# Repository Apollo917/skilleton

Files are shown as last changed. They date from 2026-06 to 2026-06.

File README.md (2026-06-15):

<div align="center">

# Skilleton 10" Server Rack Framework

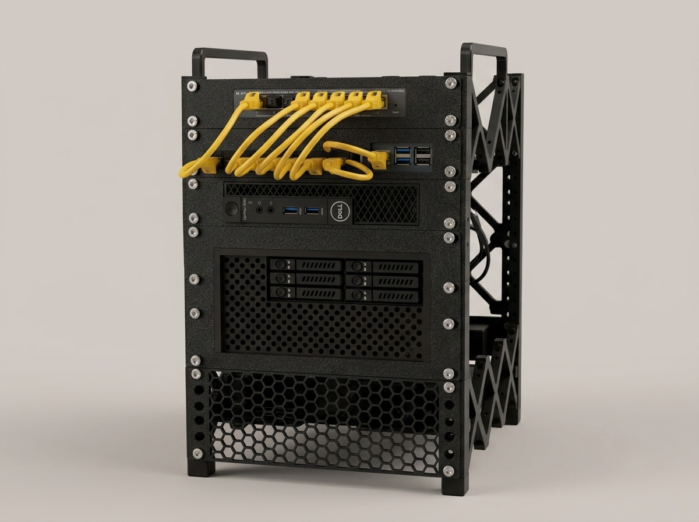
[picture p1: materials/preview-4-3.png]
Shelf mounts


</div>
<br>

**Skilleton** is a fully open-source, 3D-printable framework designed for constructing custom server and network racks
for homelab environments. Built around a modular 1U-factor grid, it allows users to scale, stretch, and compose
enclosures tailored precisely to specific hardware footprints

While optimized natively for 10-inch hardware, Skilleton avoids rigid dimension locks. Its height, width, and depth are
entirely defined by swappable, modular structural segments, making the system fully customizable

🚀 **Key Specifications & Features**

- **1U Grid Modularity:** Highly extensible layout based on standard 1U height intervals
- **Fully Custom Dimensions:** Adaptable width, depth, and height via interchangeable segments to fit non-standard
  hardware
- **Hardware Integration:** Features an integrated captive nut design for robust component mounting and assembly
- **100% 3D Printable:** Optimized for standard desktop 3D printers without requiring specialized manufacturing tools
- **Open Source:** Fully accessible architecture for community modifications and custom segment developments

🏋 **Structural Integrity & Load Ratings**

- **Component Static Load:** Standalone structural PETG segments successfully completed static load testing at **12kg**
  with zero structural failure or permanent deformation
- **Assembled Assembly Capacity:** In active deployment, a fully assembled PETG 8U Skilleton configuration continuously
  supports a **9kg** multi-node homelab setup without structural fatigue

<details>
<summary>Skilleton 8U Server Rack</summary>

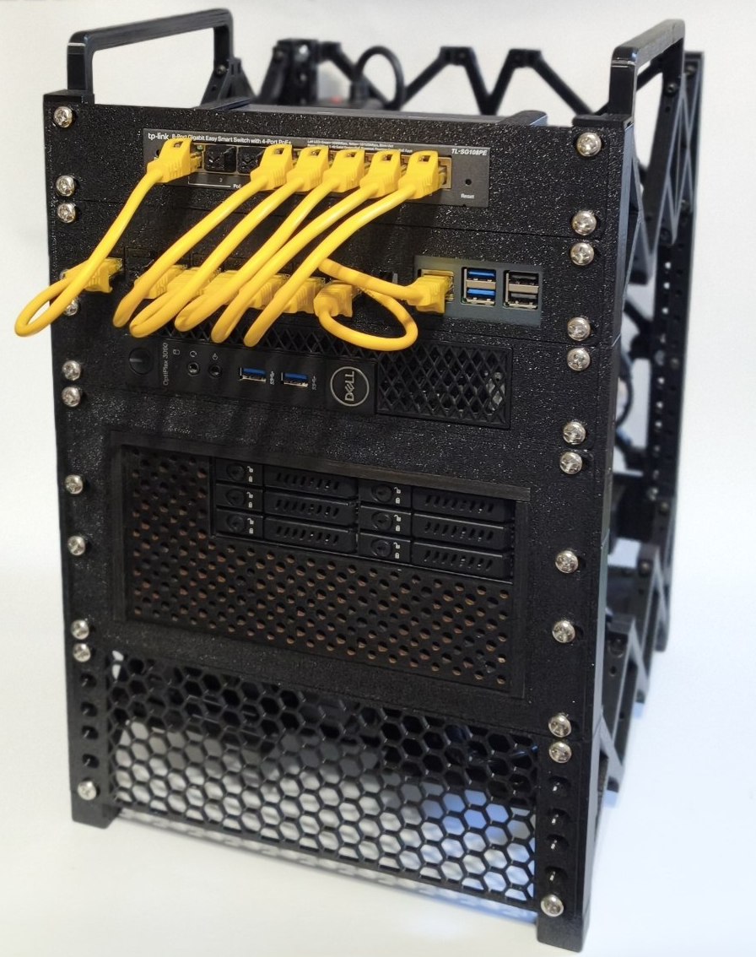
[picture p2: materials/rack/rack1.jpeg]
rack1

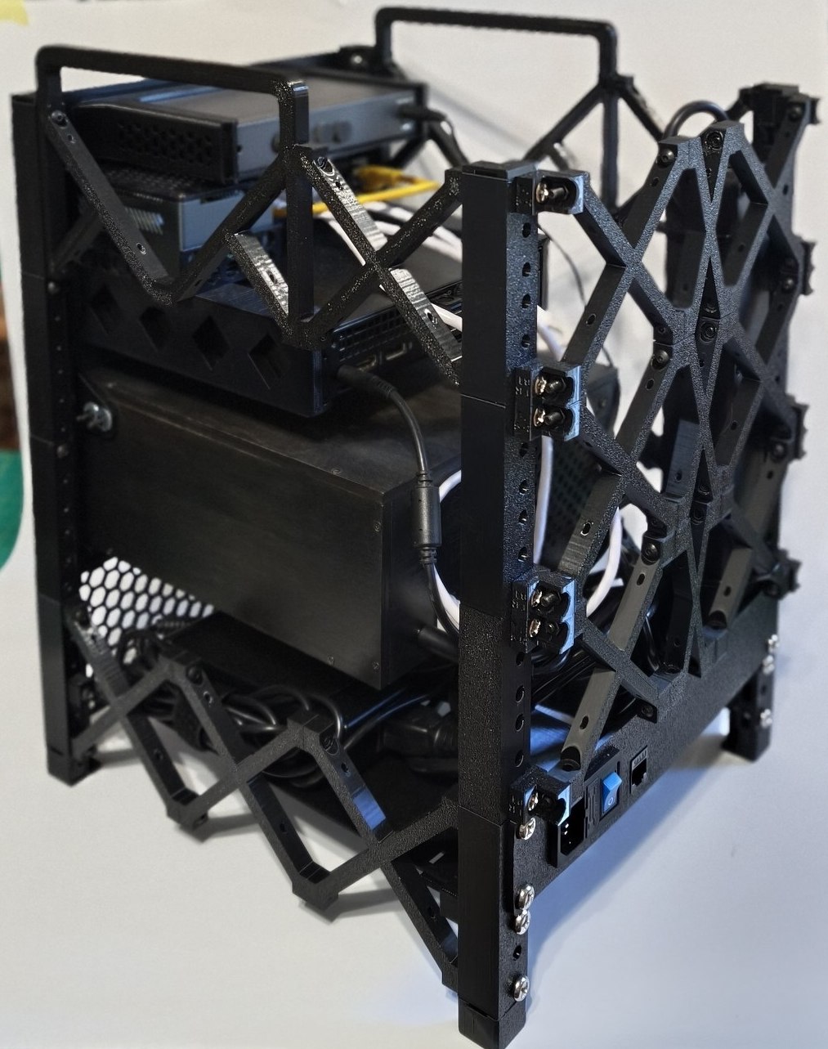
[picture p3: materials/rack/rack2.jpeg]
rack2

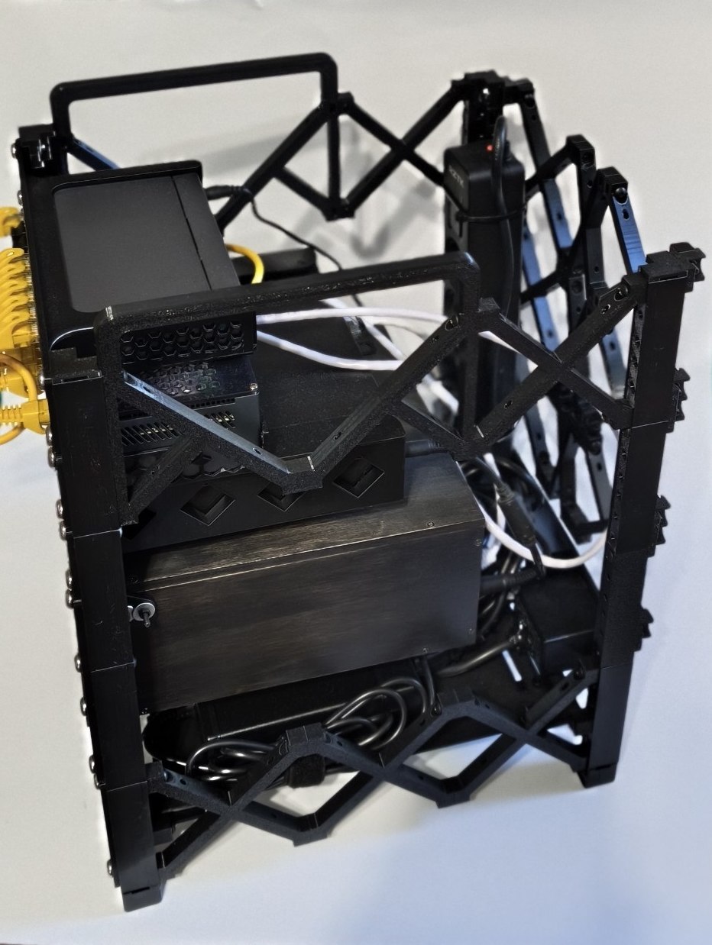
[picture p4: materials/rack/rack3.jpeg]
rack3

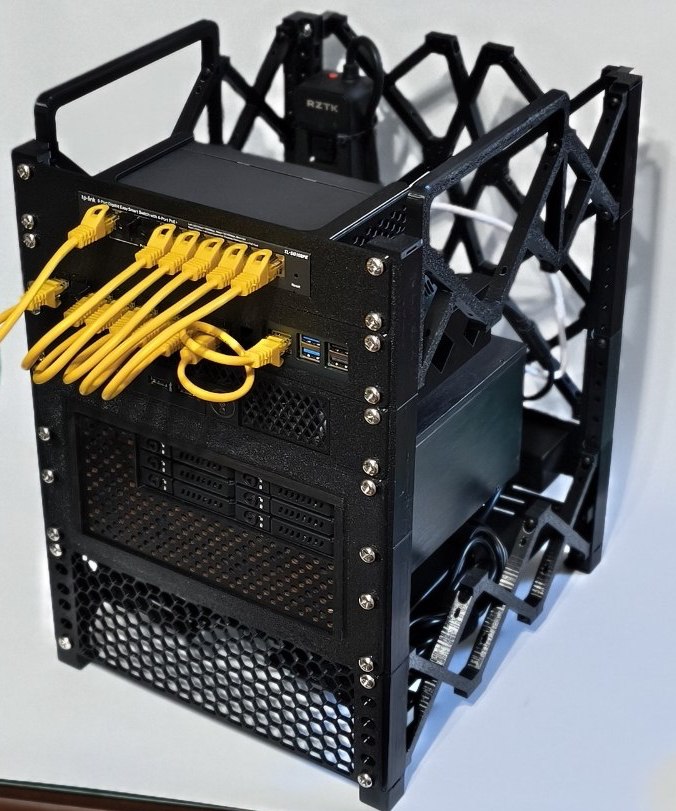
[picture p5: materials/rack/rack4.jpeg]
rack4

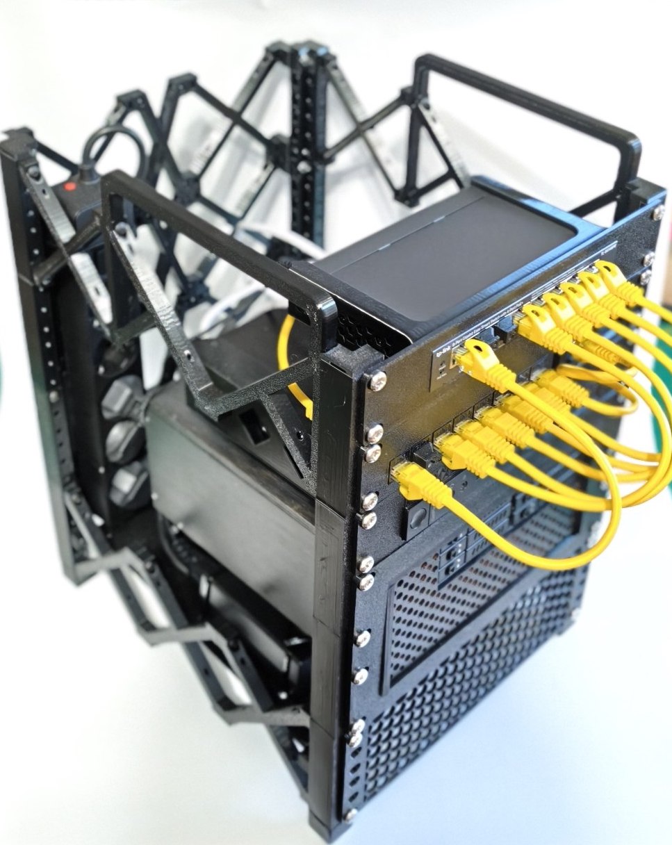
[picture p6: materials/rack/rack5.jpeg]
rack5

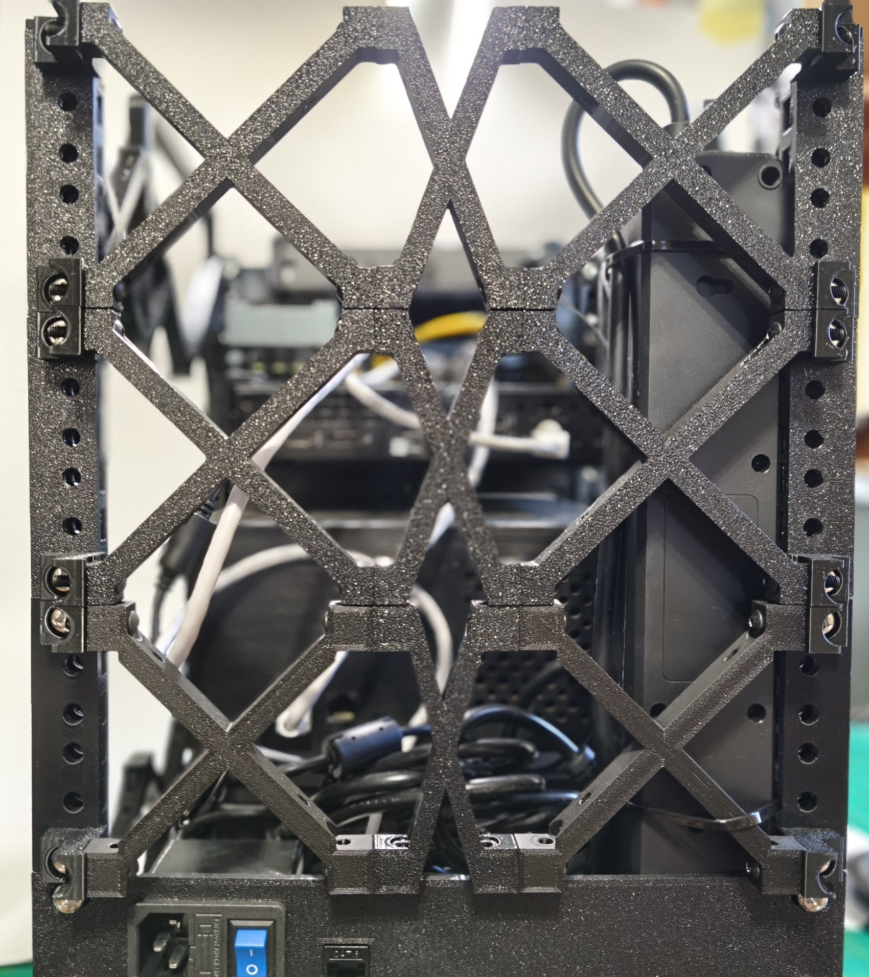
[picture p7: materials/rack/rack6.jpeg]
rack6

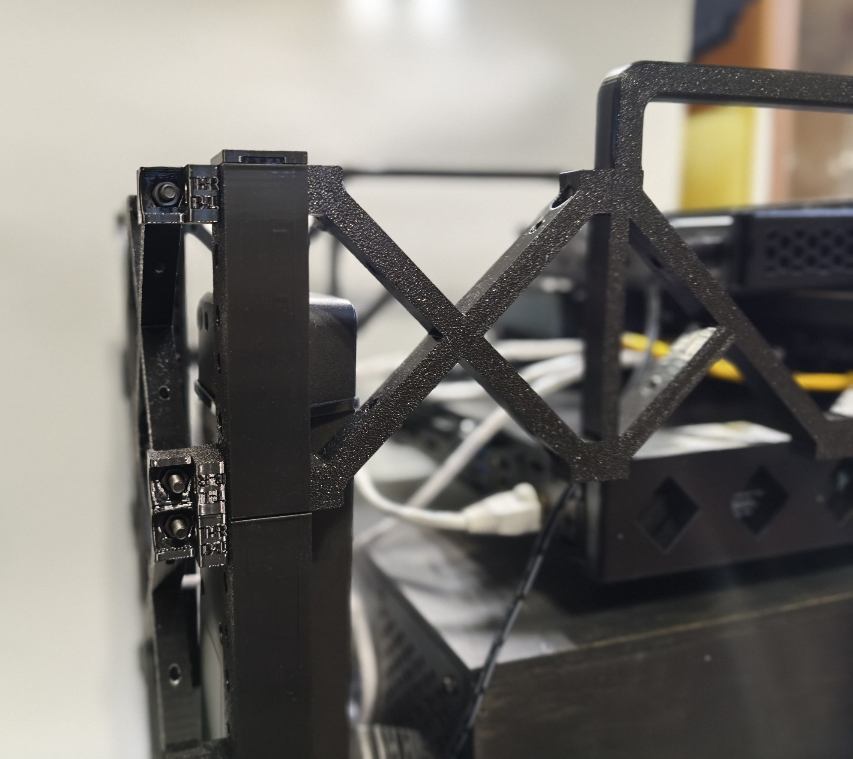
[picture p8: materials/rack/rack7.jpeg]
rack7

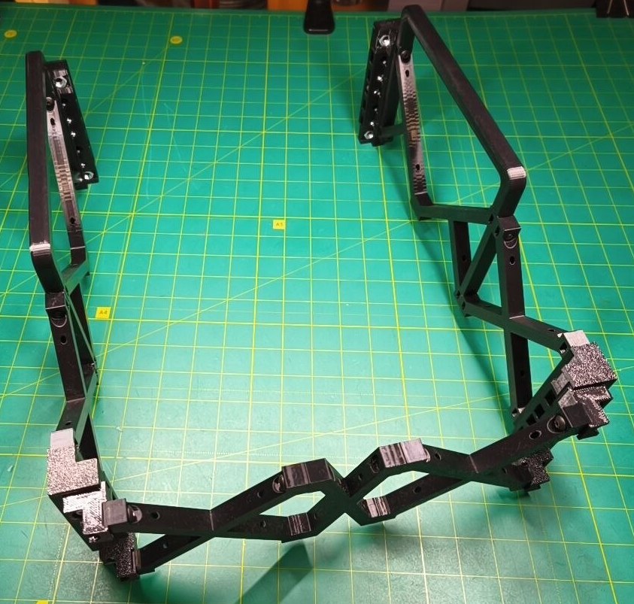
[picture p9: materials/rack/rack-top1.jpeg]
rack-top1

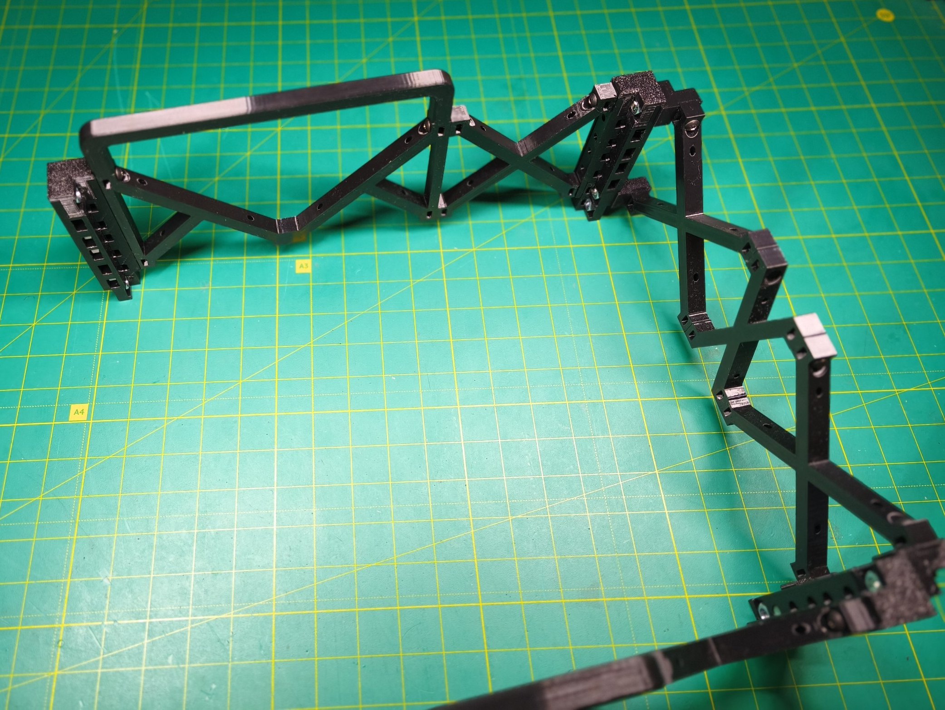
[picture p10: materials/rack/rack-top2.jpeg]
rack-top2


</details>

## 🔗Links

- [Skilleton on MakerWorld](https://makerworld.com/en/models/2936394-skilleton-10-server-rack-framework#profileId-3288012)
- [Skilleton on Printables](https://www.printables.com/model/1755132-skilleton-10-server-rack-framework)

## ⚙️ Print Specifications

A standard 6U Skilleton 10-inch rack configuration requires:

- **Filament:** ~700g of PETG (or technical filaments with equivalent mechanical properties)
- **Time:** ~26 hours
- **Layer Height:** 0.2mm
- **Infill:** 30% Gyroid
- **Wall Loops:**
    - **5 walls** for all handle components
    - **4 walls** for all other structural components

## 🔩 Bill of Materials

Aside from the filament, assembling the **Skilleton** rack requires only standard metric fasteners. All
integrated slots are engineered to fit standard DIN 934 hex nuts, removing the need for proprietary hardware or heat-set
tools

### Material Types

- M4 x 20mm screws
- M4 nuts DIN 934 hex nuts
- M6 x 16mm screws
- M6 nuts DIN 934 hex nuts

### Baseline Quantities [(for a 6U 10-inch configuration)](files/6U-rack-bundle.3mf)

- **M4 x 20mm screws and nuts:** **~60 pieces are required** to connect all structural supports, stands, and connectors
- **M6 x 16mm screws and nuts:** **A minimum of 16 pieces is strictly required** to properly secure the main server rack
  stands, feet and caps. The total additional amount depends entirely on how many rackmount devices, panels, or
  adapters you plan to install

## 📦 Files

- [6U 10-inch server rack bundle Bambu Studio .3mf file](files/6U-rack-bundle.3mf)
- [All available components bundle Bambu Studio .3mf file](files/skilleton.3mf)
- [Autodesk Fusion .f3d file](files/skilleton.f3d)
- [.step file](files/skilleton.step)

## 🧩 Available Components

### Stands

The primary vertical structural elements that dictate the rack's Rack Unit (RU) capacity and provide the main mounting
interface for equipment

- **Standard Rack Compliance:** Engineered to follow standard server rack vertical spacing specifications, serving as
  the native mounting interface for rack-mountable hardware
- **M6 Equipment Sockets:** Features dedicated, integrated captive sockets for standard M6 screws and nuts to securely
  fasten rack units
- **M4 Accessory & Support Sockets:** Equipped with integrated M4 screw and nut sockets. These serve a dual purpose:
  securing the rack's horizontal structural supports and acting as modular extension points for attaching side panels,
  cable management, or custom add-ons
- **Mirrored Geometry:** Due to their asymmetrical structural design, these components are delivered as distinct left-
  and right-handed parts. They must be printed in mirrored pairs to assemble a functional rack layer
- **Modular Grid Configurations:**
    - 1U
    - 2U

#### Preview

<details>
<summary>Printed</summary>

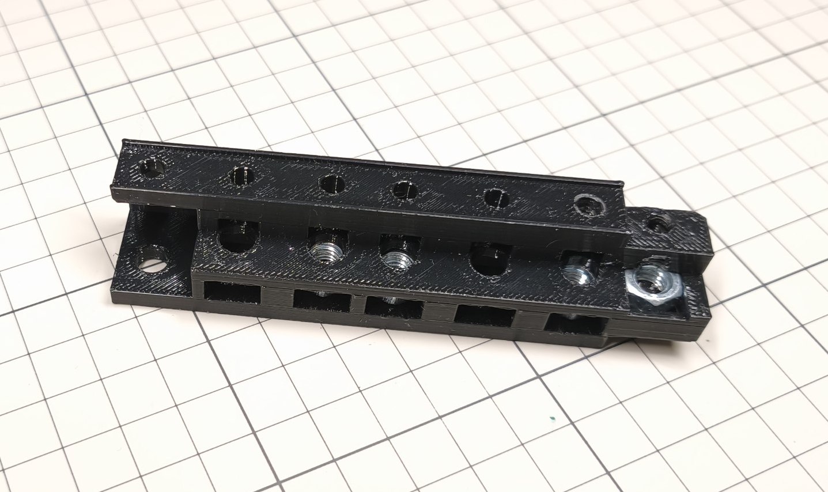
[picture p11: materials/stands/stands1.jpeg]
stands1

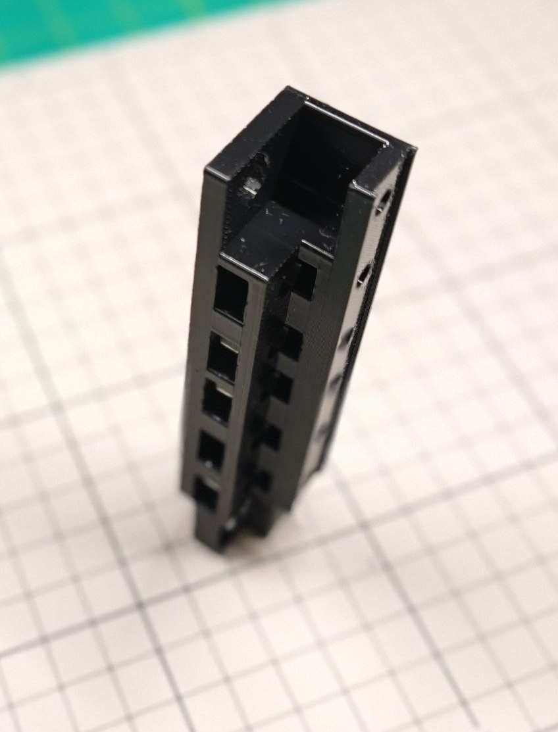
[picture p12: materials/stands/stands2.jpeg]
stands2

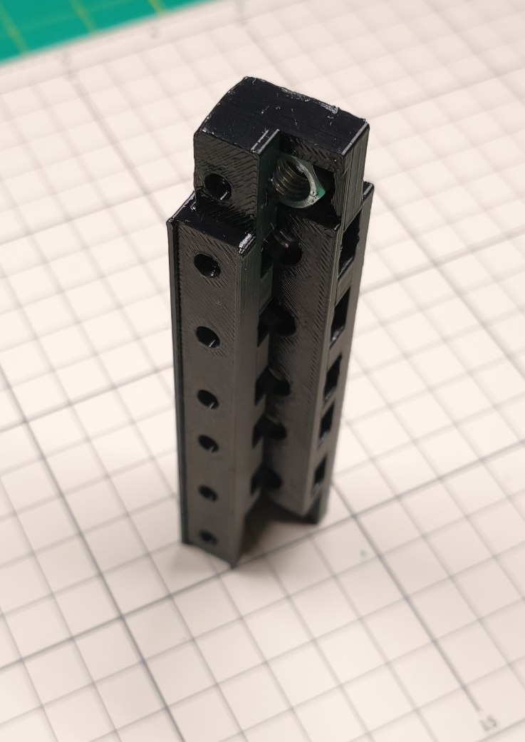
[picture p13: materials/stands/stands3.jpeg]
stands3

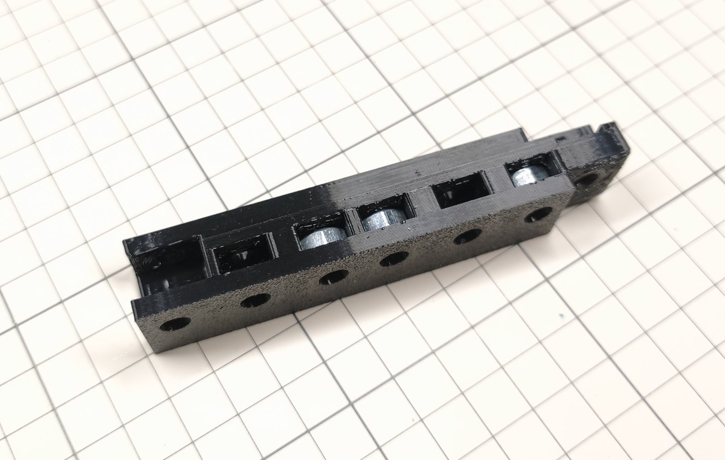
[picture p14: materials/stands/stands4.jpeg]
stands4

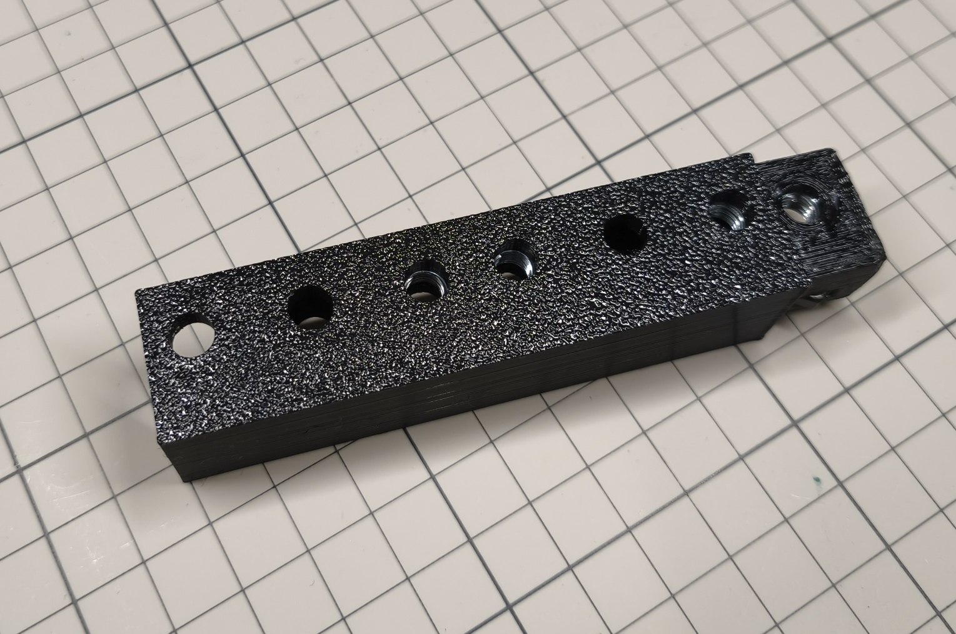
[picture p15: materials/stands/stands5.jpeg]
stands5

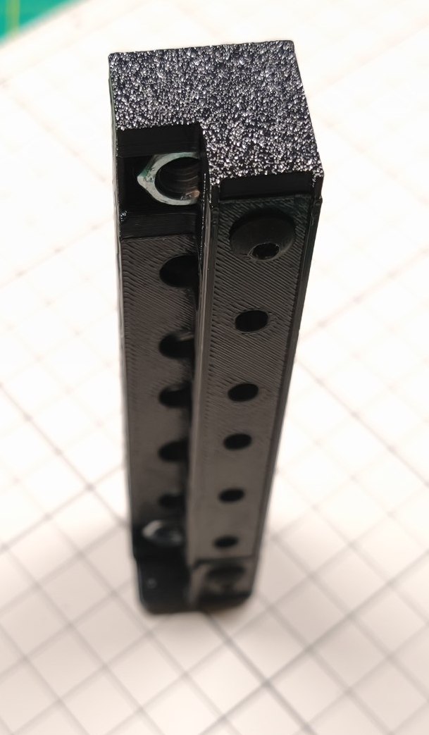
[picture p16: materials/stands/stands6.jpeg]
stands6

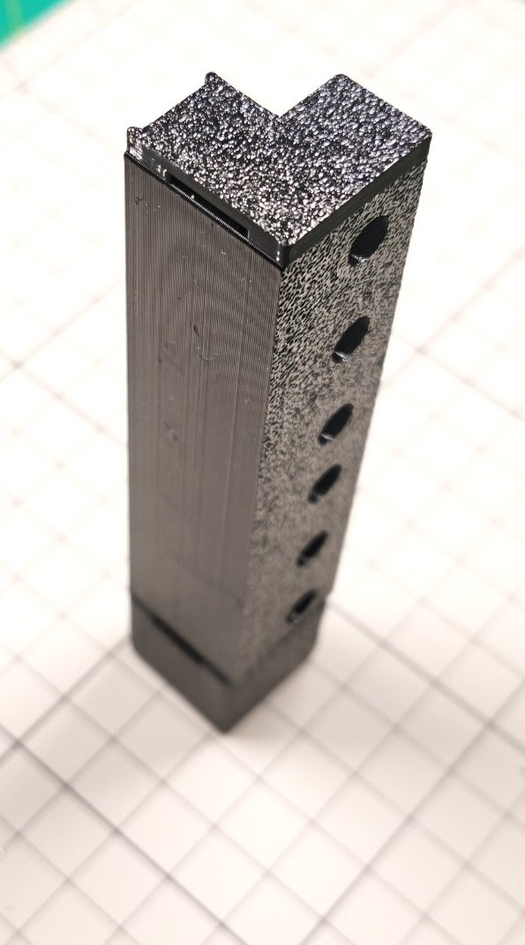
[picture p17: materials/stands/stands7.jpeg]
stands7

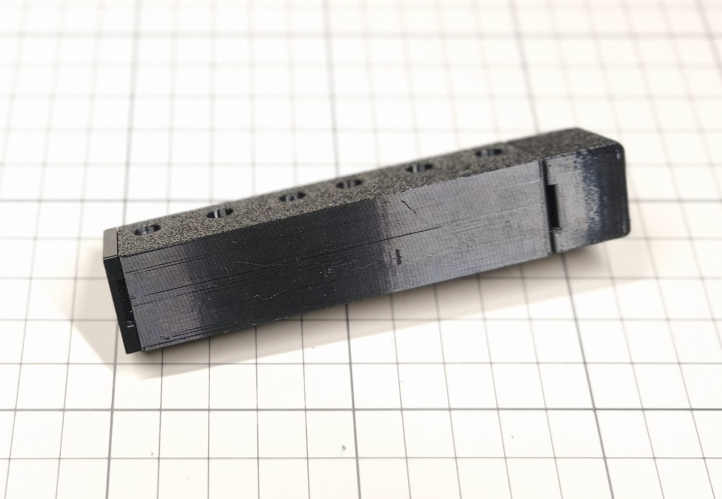
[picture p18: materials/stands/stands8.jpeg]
stands8

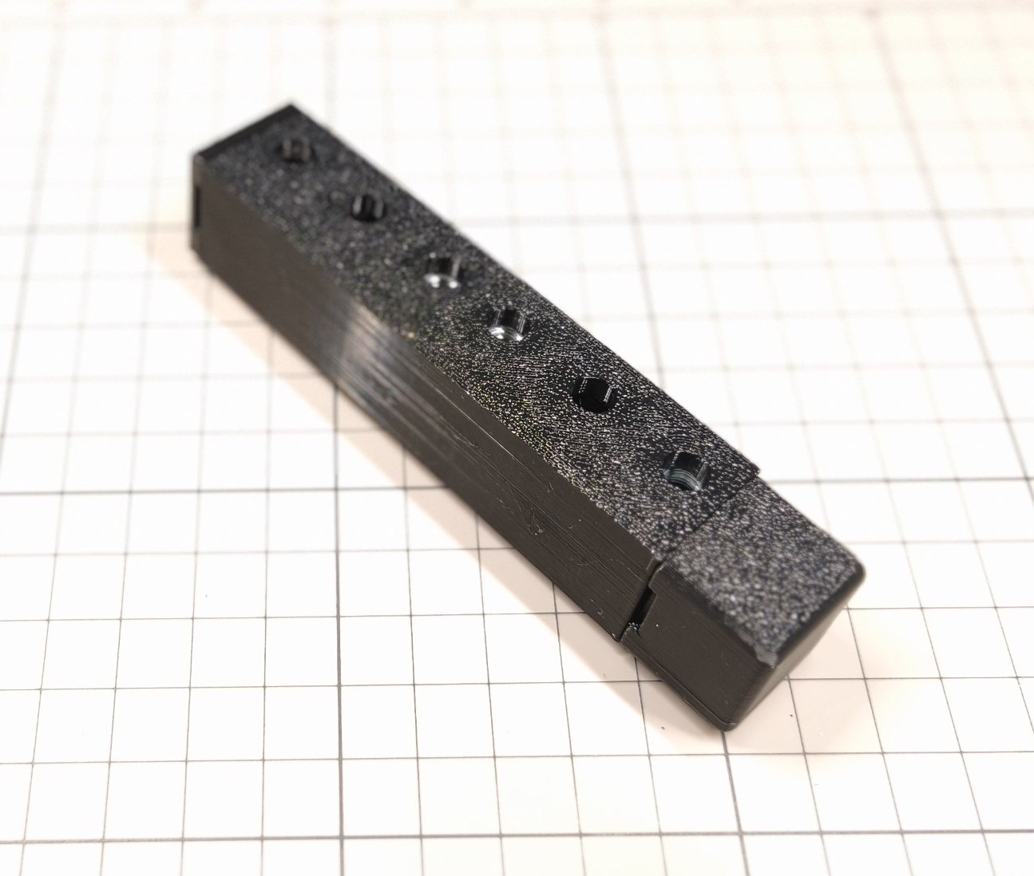
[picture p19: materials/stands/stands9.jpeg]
stands9


</details>

<details>
<summary>3D</summary>

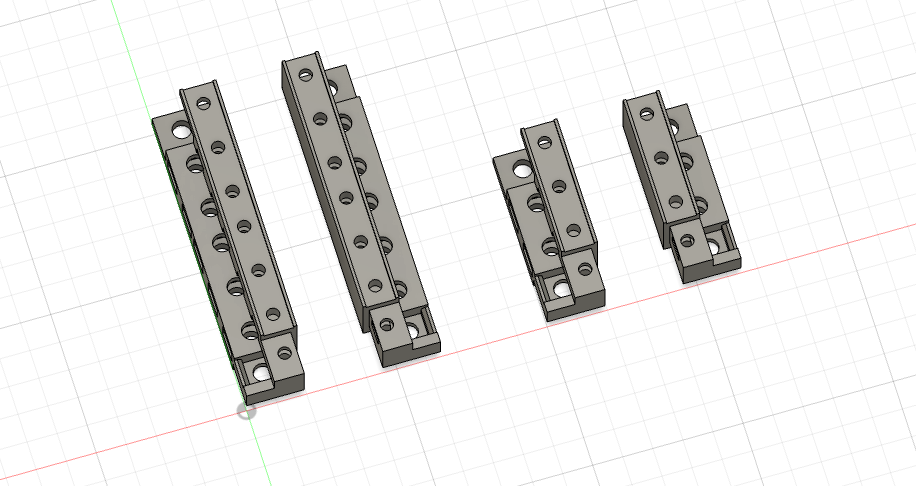
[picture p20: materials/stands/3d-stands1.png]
3d-stands1

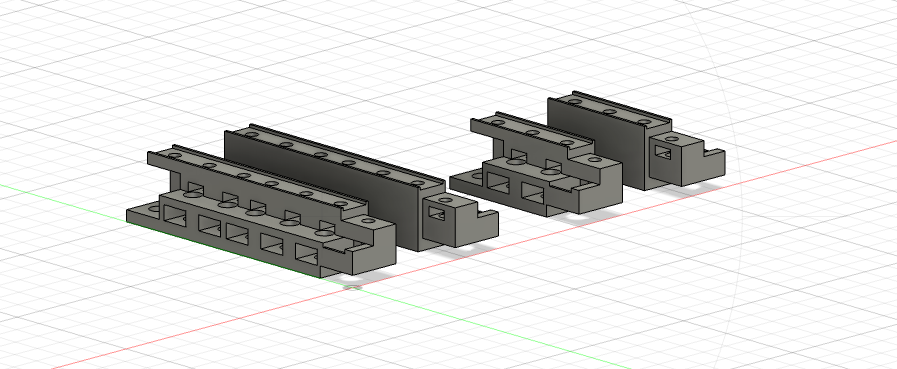
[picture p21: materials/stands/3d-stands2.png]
3d-stands2

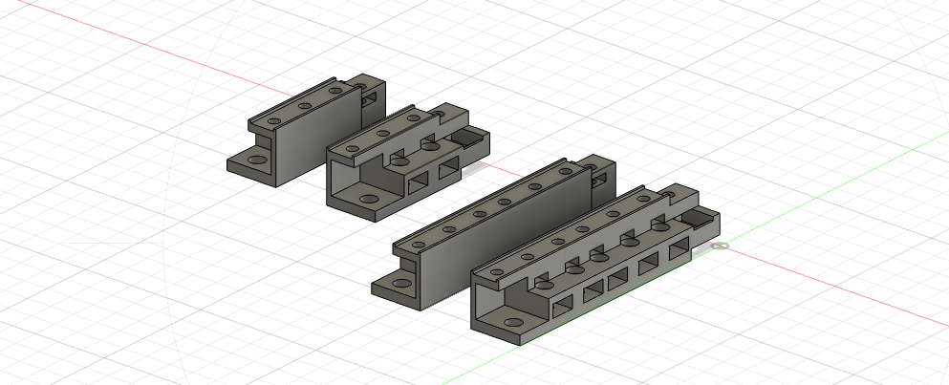
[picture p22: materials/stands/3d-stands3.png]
3d-stands3


</details>

### Supports

The structural cross-members that bridge the vertical stands to establish the rack's footprint and ensure overall
framework rigidity

- **Dimensional Definition:** Acts as the primary components that dictate both the total width and total depth of the
  server rack configuration
- **Horizontal Stability:** Provides critical lateral bracing to eliminate structural sway and maintain square alignment
  under load
- **Modular Grid Configurations:** Available in multiple width x height sizing options to allow for custom modular
  scaling:
    - 2x2U
    - 2x1U
    - 1x2U
- **Integrated Cable Management:** Features molded pass-through 3mm holes optimized for zip ties or hook-and-loop
  fasteners to facilitate clean internal cable routing

#### Preview

<details>
<summary>Printed</summary>

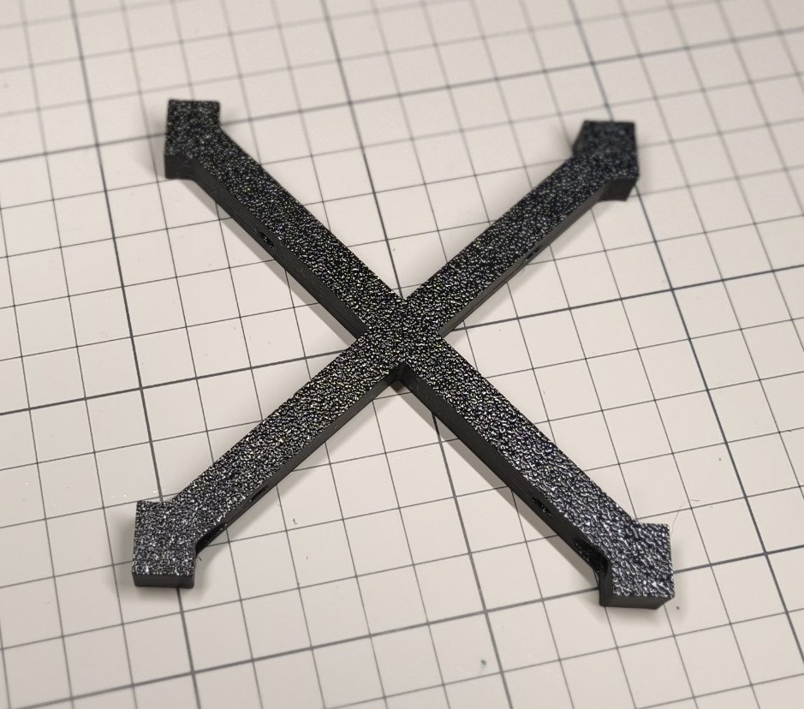
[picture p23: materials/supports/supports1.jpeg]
supports1

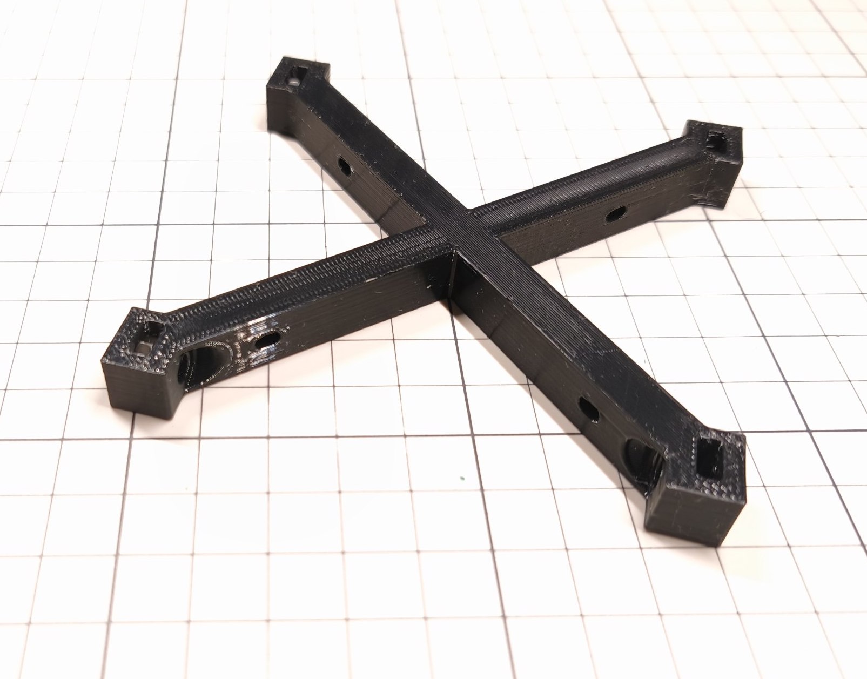
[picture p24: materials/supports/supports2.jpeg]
supports2

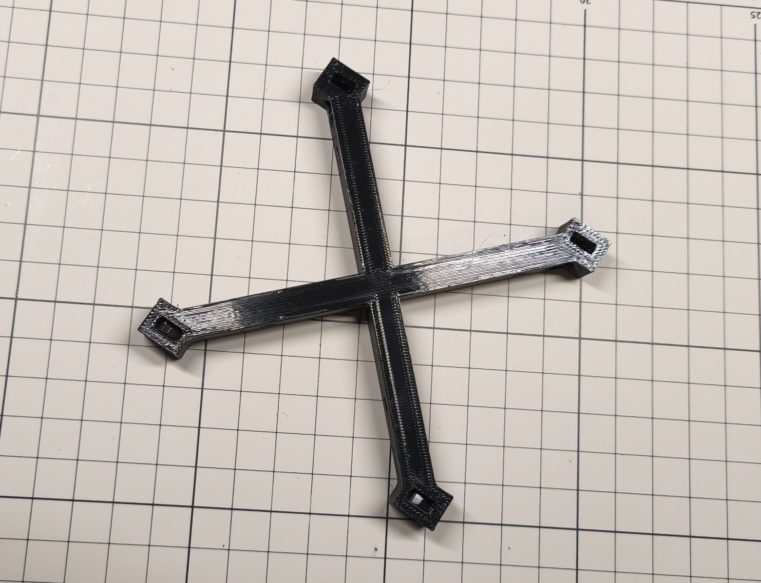
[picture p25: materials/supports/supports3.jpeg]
supports3

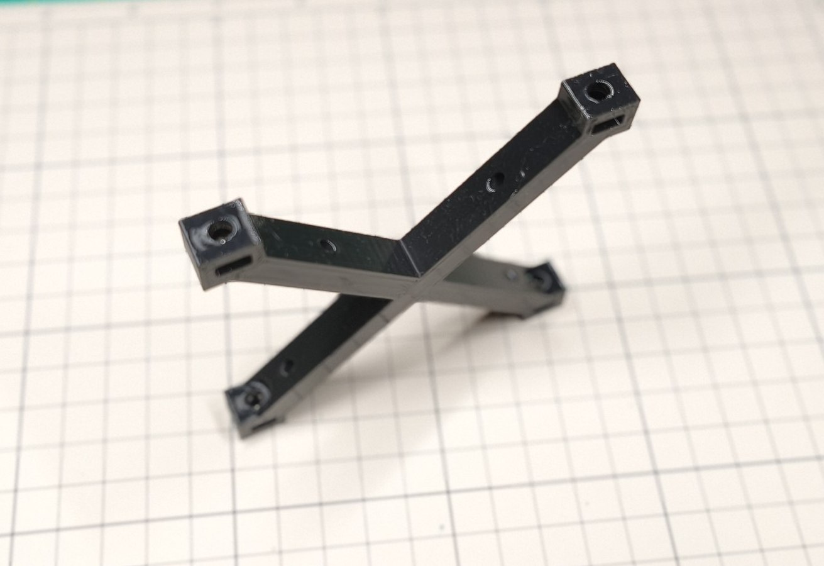
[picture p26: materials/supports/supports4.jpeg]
supports4


</details>

<details>
<summary>3D</summary>

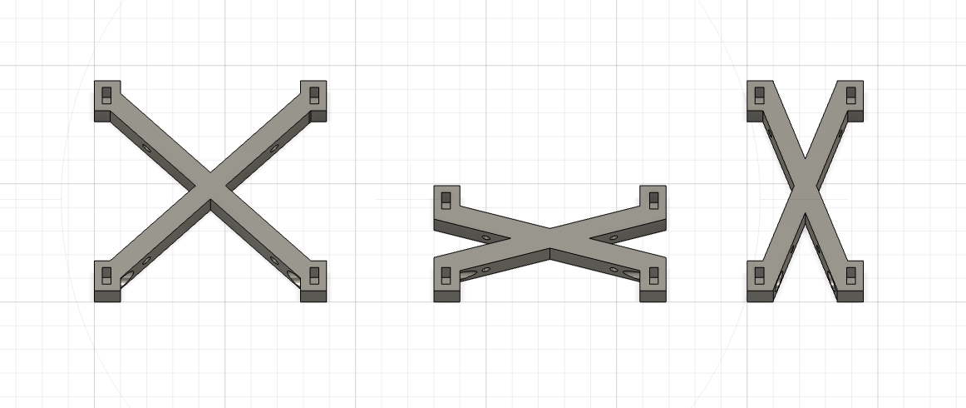
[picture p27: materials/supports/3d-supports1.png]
3d-supports1

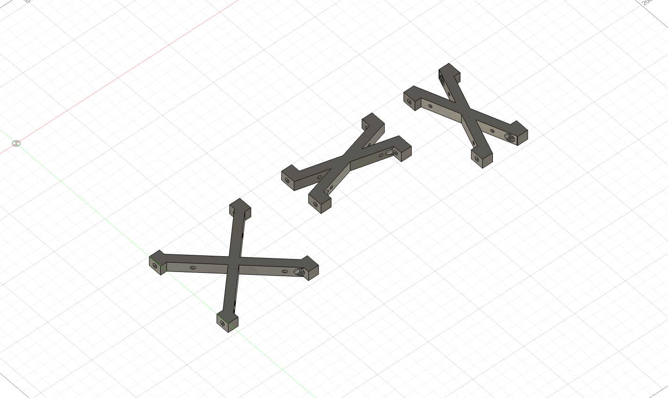
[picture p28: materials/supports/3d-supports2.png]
3d-supports2

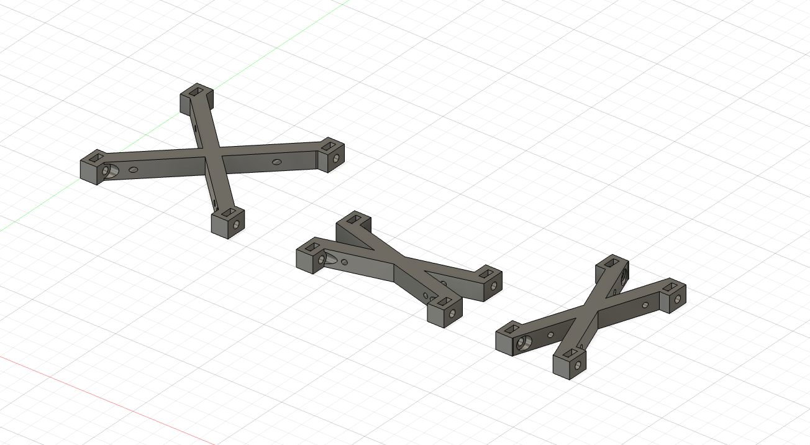
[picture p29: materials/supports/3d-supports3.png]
3d-supports3


</details>

### Handles

Dual-purpose components that integrate directly into the framework's horizontal layout, serving simultaneously as
structural cross-members and lifting points

- **Structural Integration:** Designed to merge seamlessly into the support composition, functioning actively as a
  load-bearing element that maintains overall frame rigidity
- **Dual-Function Design:** Eliminates the need for dedicated, non-structural add-ons by acting as both a standard
  framework support and a robust transport grip
- **Modular Grid Configurations:** Available in multiple scaling options (width x height) to match your custom support
  layout:
    - 2x2U
    - 2x1U
    - 4x2U
    - 4x1U

#### Preview

<details>
<summary>Printed</summary>

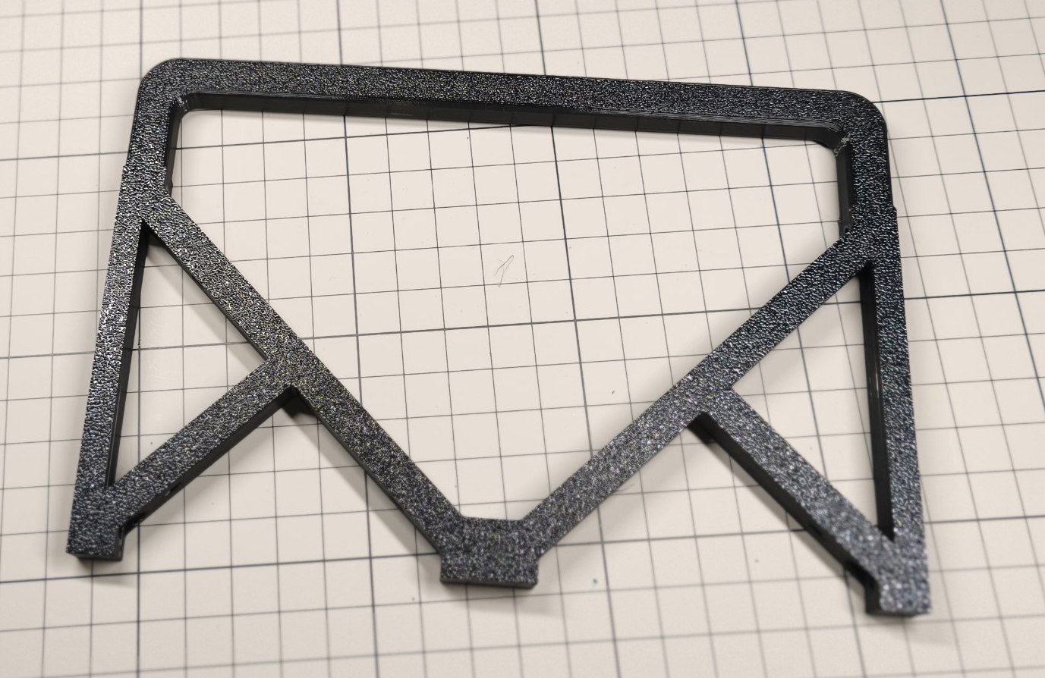
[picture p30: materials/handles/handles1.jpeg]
handles1

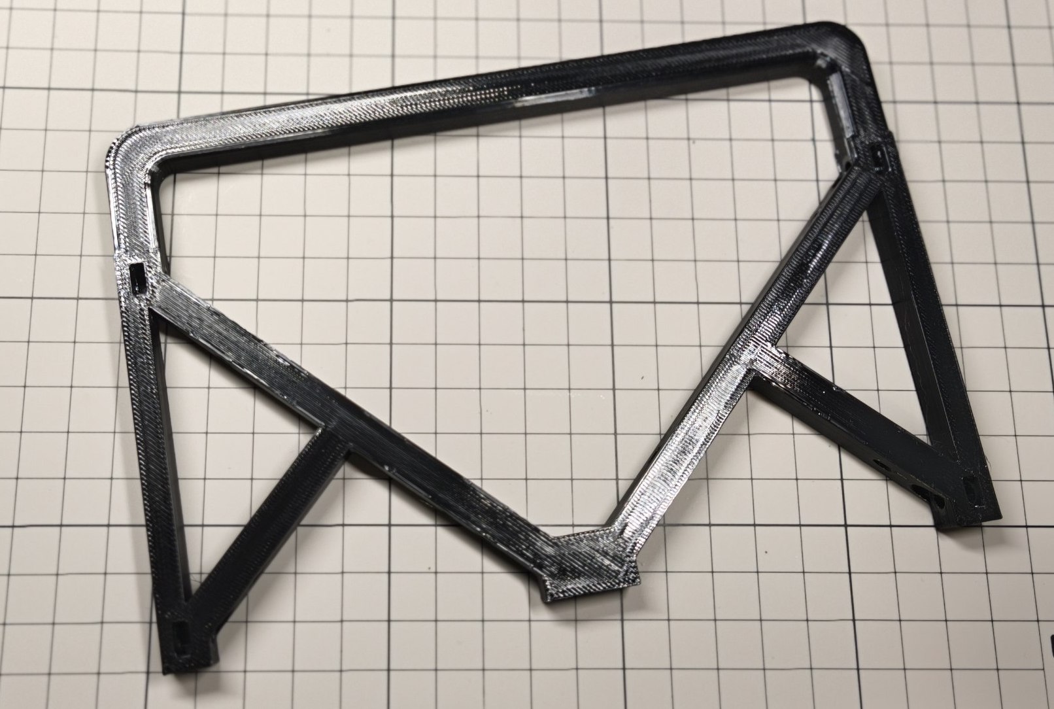
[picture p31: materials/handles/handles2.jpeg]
handles2

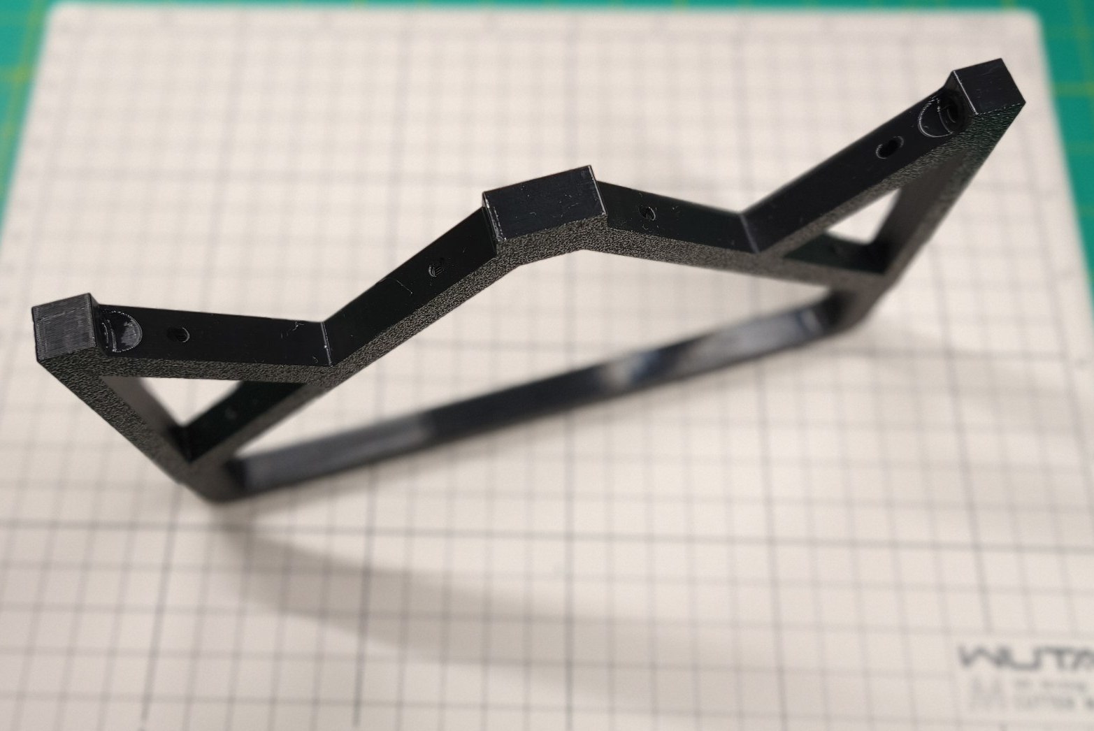
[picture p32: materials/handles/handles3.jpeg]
handles3


</details>

<details>
<summary>3D</summary>

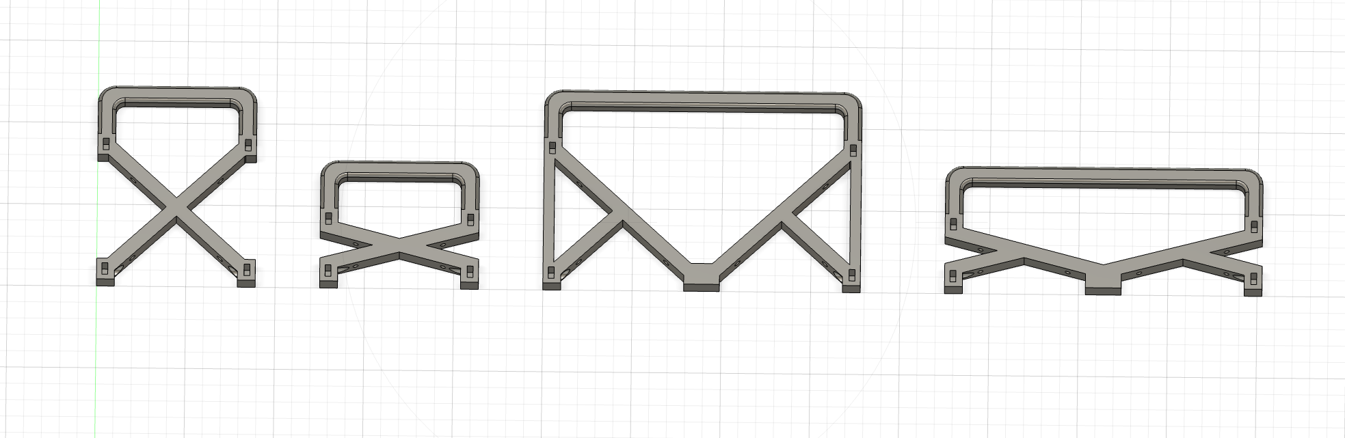
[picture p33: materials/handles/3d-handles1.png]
3d-handles1

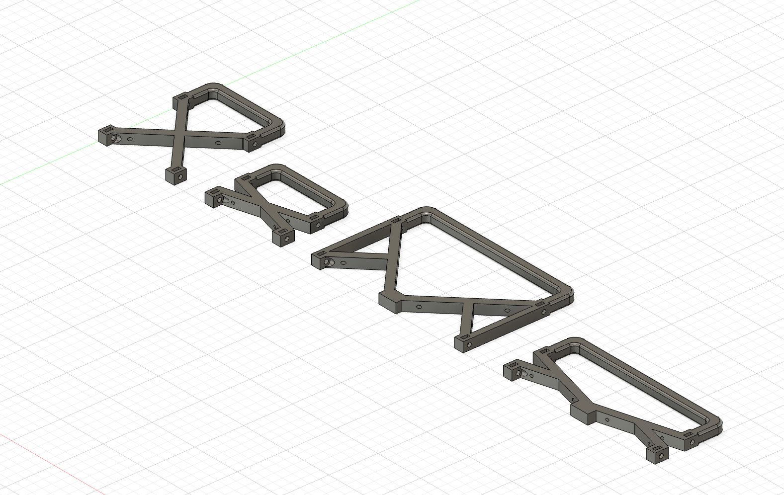
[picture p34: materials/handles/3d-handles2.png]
3d-handles2

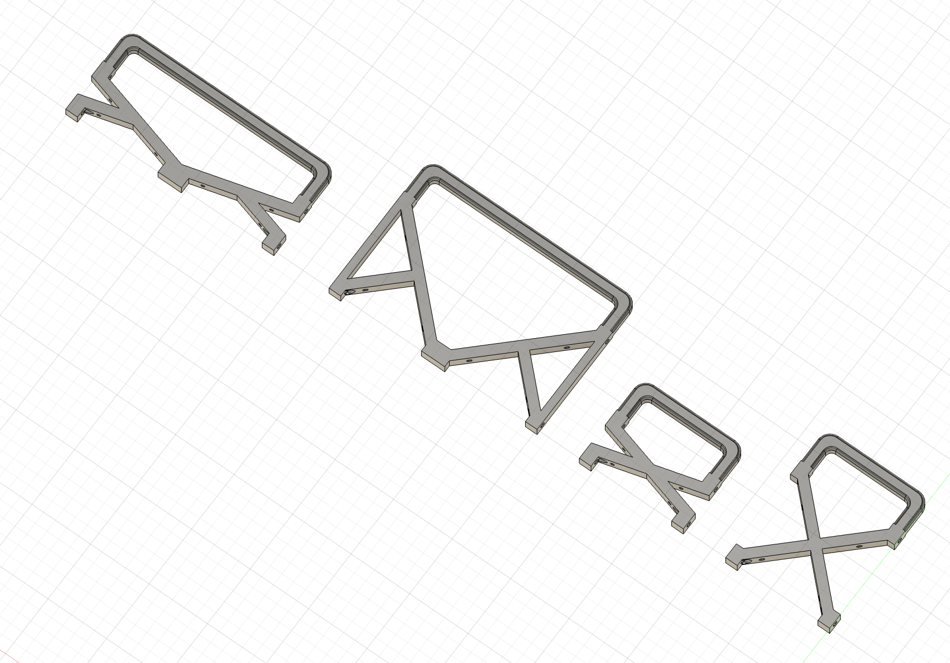
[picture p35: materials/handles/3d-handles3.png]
3d-handles3


</details>

### Adapters & Spacers

Auxiliary structural components designed to accommodate specific hardware configurations and geometric transitions
within the framework

**Back Support Adapters**

- **Purpose:** Enables horizontal support segments to function as a rear back-plate
- **Orientation & Marking:** Produced as mirrored components with integrated orientation markings relative to the stand
  position: TL (Top Left), TR (Top Right), BL (Bottom Left), and BR (Bottom Right)
- **Assembly Tolerance:** The geometric variations between these four adapters are minimal. Due to the intrinsic
  flexibility of the 3D-printed stands, these orientation markings can be safely ignored during assembly, as the
  material easily compensates for the minor structural differences

**Spacers**

- **Purpose:** Fastener length compensation inserts used when securing the vertical stands
- **Hardware Compatibility:** Required specifically when assembling the framework with M4 x 20mm screws and nuts
- **Optional Substitution:** These components are entirely optional; users can eliminate the need for spacers by
  substituting the hardware with shorter M4 x 10mm screws

#### Preview

<details>
<summary>Printed</summary>

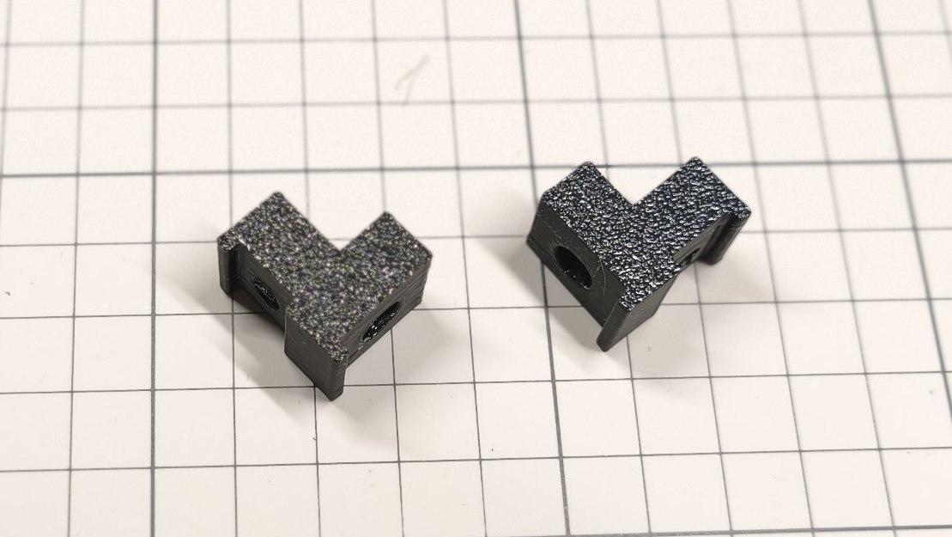
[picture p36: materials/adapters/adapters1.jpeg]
adapters1

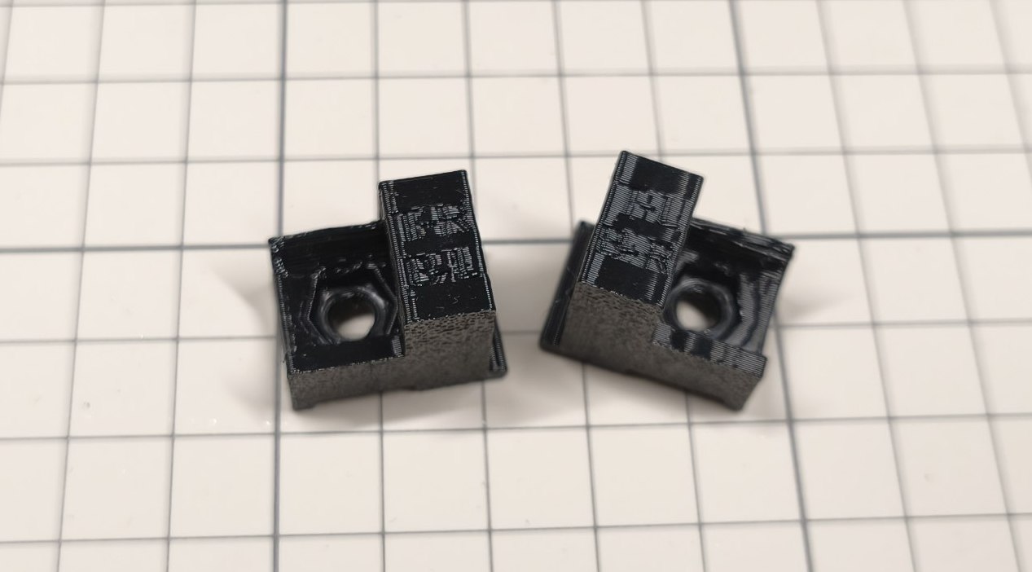
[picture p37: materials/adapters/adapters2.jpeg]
adapters2

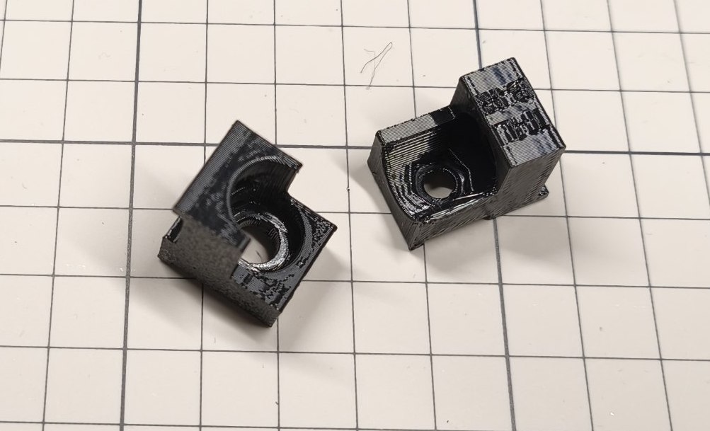
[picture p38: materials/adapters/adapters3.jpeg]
adapters3


</details>

<details>
<summary>3D</summary>

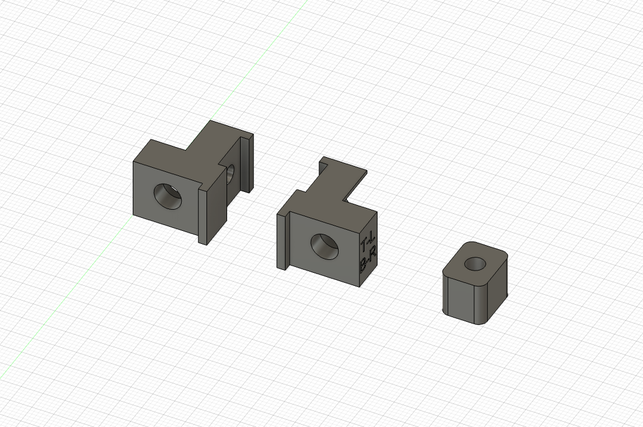
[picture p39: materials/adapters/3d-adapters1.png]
3d-adapters1

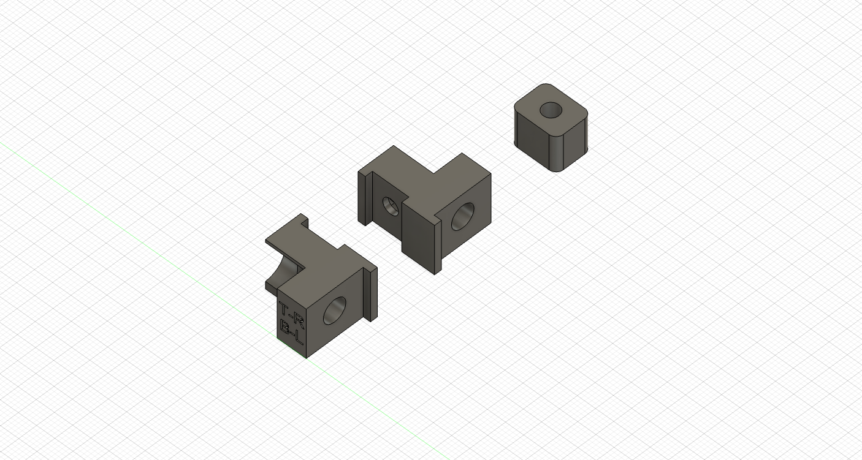
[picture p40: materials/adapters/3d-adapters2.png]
3d-adapters2


</details>

### Stand Feet

Base components designed to provide a secure and stable foundation for the assembled framework. Functions as the direct
contact interface with the desk or floor, protecting supporting surfaces from scratches

#### Preview

<details>
<summary>Printed</summary>

feet1
feet2

</details>

<details>
<summary>3D</summary>

3d-feet1
3d-feet2

</details>

### Stand Caps

Termination components designed to cap the upper edges of the vertical stands while maintaining hardware mounting
functionality

- **Top-Edge Mounting Interface:** Provides integrated sockets for M6 and M4 screws and nuts at the very top of the
  framework

#### Preview

<details>
<summary>Printed</summary>

caps1
caps2

</details>

<details>
<summary>3D</summary>

3d-caps1
3d-caps2
3d-caps3

</details>

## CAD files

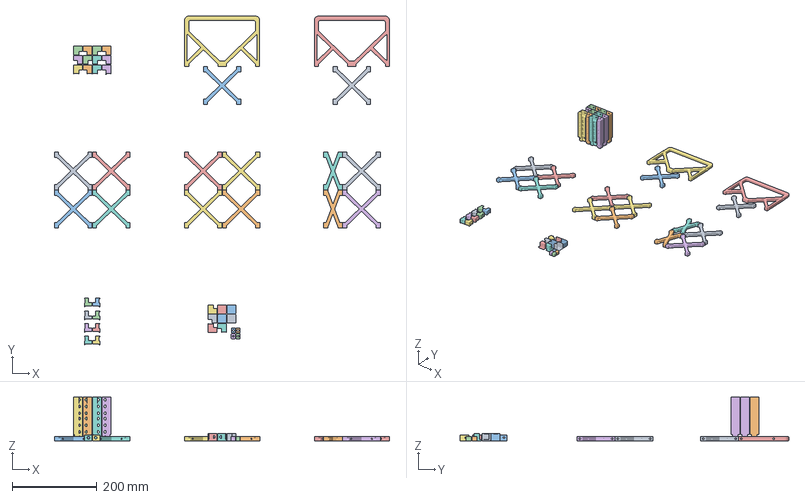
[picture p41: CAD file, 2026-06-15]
files/6U-rack-bundle.3mf
792.7 x 778.3 x 103.8 mm
support-2-2 x 12
stand-left-2U x 6
foot-left x 2
stand-right-2U x 6
handle-4-2 x 2
foot-right x 2
cap-right x 4
secondary-stand-holder-adapter x 4
support-corner-adapter-TR-BL x 4
support-1-2 x 2
support-corner-adapter-TL-BR x 4

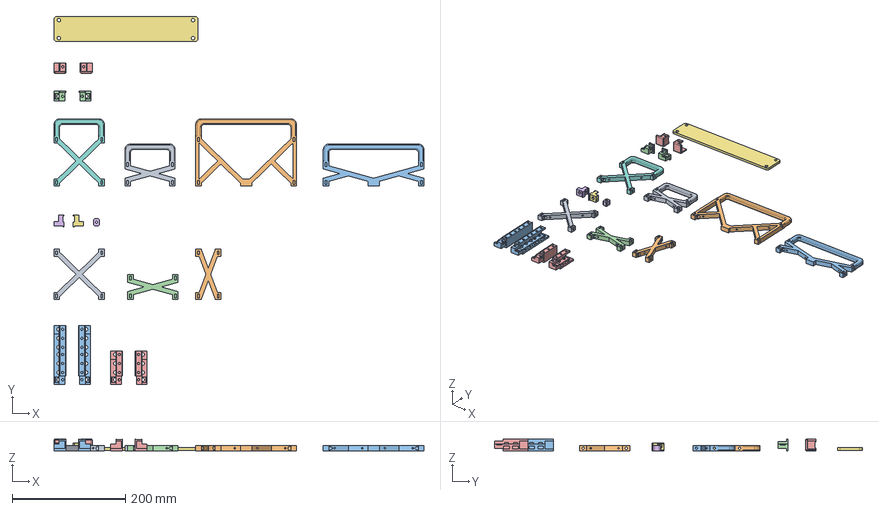
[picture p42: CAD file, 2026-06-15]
files/skilleton.step
652.8 x 649.5 x 21.3 mm

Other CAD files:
files/skilleton.3mf
files/skilleton.f3d
